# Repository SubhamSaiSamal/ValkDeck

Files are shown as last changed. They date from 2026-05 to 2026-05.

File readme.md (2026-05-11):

# VALKDECK 

Hey there, I'm Subham, a 14 year old kid (currently) from Chennai, India

I needed a better way to manage my flight sim telemetry, trigered automation workflows, and also blindly control my volume while locked into a game. I could have bought a generic macropad off Amazon for $20.

Instead, I spent 40 hours learning KiCad, routing my own custom PCB, designing an enclosure in onshape, and writing a CircuitPython program from scratch.

Welcome to *ValkDeck.*

It's a 9-key, fully hotswappable cyberdeck module powered by a Raspberry Pi Pico. It features per=key WS2812B underglow, a rotary encoder for media control, and a 0.91" I2C OLED display that feeds back live system status so I can actually know what my macros are doing.

ValkDeckFull

# FEATURE PIVOT

If you look at the top right of the board, you'll see a machined metal blanking plug.

Originally, that 12mm hole was meant for a massive, avionics-grade MTS-101 toggle switch (the "Nuke Switch") to act as a hardware reset. I measured the top plate perfectly. What i *forgot* to measure was the internal Z-axis clearance. The massive rectangular block of the toggle switch slammed right into the PCB.

Physical reality remains undefeated. Instead of spending the next 6 hours rearranging the whole top-case, I pivoted. I covered it with a sleek metal plug for a premium industrial look. It's not a bug; it's an aesthetic hardware change.

[OnshapeCase](https://cad.onshape.com/documents/f17dd9f4e6cb3dbe968d54ad/w/35238b8d1c489f2cc410f163/e/0b39d0bd7ba726a80e99828b)

# THE PCB

PCB

PCB_FRONT

PCB_BACK

I have been familiar with breadboards and scary jumper wire connections for quite a while. Instead of a terrifying 3D web of hand-soldered jumper wires, ValkDeck runs on a custom-routed, two layer FR-4 board.

Bottom-Mount SMD     : The kailh hotswap sockets and 1N4148 diodes are all surface mounted on the upperside of the board. 
Ghost-Free Matrix    : The diodes are correctly routed (Row to Column) to ensure complete N-key rollover without ghosting.
Through-Hole Anchors : The Raspberry Pi Pico, Rotary Encoder, and OLED screen are all through-hole soldered for maximum regidity 💪.

# HARDWARE

ValkDeck runs on a custom FR-4 PCB with a proper diode-protected switch matrix.

- The Brain   : Raspberry Pi Pico (RP2040)
- The Matrix  : 9x Kailh Hotswap Sockets (with 1N914 diodes pointing Row -> Col)
- The Display : 0.91" SSD1306 OLED (128x32)
- The Input   : 9x Mechanical Switches 
                 1x M274 Rotary Encoder (with push-to-mute)
- The RGB     : 9x WS2812B NeoPixels
- The Alert   : 1x Active Buzzer for audio feedback (and 8 bit pokemon and mario sfx)

# PINOUT ARCHITECTURE

If you're trying to understand the exact tracing or trying to make your very own ValkDeck, here is the routing:

| Component | Pico Pin (GPIO) | Note |
| :--- | :---: | ---: |
| Matrix Rows | GP09, GP10, GP11 | Row 0,1,2 |
| Matrix Cols | GP00, GP01, GP02 | Col 0,1,2 |
| Encoder | GP04(A), GP03(B), GND(C), GND(S2), GP05(S1)  | Volume sweeping and mute |
| OLED | GP16(SCL), GP17(SDA) | Standard I2C |
| NeoPixels | GP15 | Single data line for all 9 LEDs | 
| Buzzer | GP19 | PWM Audio (retro pokemon) |



9-WS2812B

3x3_Matrix

# RUNNING THE FIRMWARE

ValkBlox is run using Adafruit's CircuitPython. It uses the keypad library for the background matrix scanning, and displayio to dynamically update the OLED based on what macro you just fired

To Deploy : 

- Flash your Pico with the latest [CircuitPython.uf2](https://learn.adafruit.com/welcome-to-circuitpython/installing-circuitpython) 

- Grab the [Adafruit Library Bundle](https://github.com/adafruit/Adafruit_CircuitPython_Bundle) and drop this stuff into your CITCUITPY/lip folder
  - adafruit_hid
  - adafruit_displayio_ssd1306.mpy
  - adafruit_display_text
  - neopixel.mpy

- Drop firmware.py from this repo to the root drive

# BOM (Bill of materials)
|Name	 |Purpose	 |Quantity	|Total Cost (USD)	|Link	 |Distributor |
| :--- | :---: | --- | --- | --- |---
|Raspberry Pi PICO |Microcontroller (Controls everything lol)	 |1	 |$4.05	 |[View Product](https://www.silverlineelectronics.in/products/raspberry-pi-pico?_pos=3&_sid=a84e46afc&_ss=r#)	 |Silverzone |
|0.91 Inch I2C OLED 	|OLED Display to display backend info 	 |1	 |$1.94	 |[View Product](https://roboticsdna.in/product/0-91-inch-iic-4-pin-oled-display-module-ssd1306-white/)	|RoboticsDNA |
|Cherry MX RGB Switch	 |Brown RBG Switch (Pack of 10) 	|1	 |$3.7	 |[View Product](https://meckeys.com/shop/accessories/keyboard-accessories/key-switches/cherry-mx-rgb-switch/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)	|Meckeys |
|Kalih Socket |Hot-Swap socket for cherry mx switches (Pack of 10) |1	 |$0.84	 |[View Product](https://meckeys.com/shop/accessories/keyboard-accessories/key-switches/kailh-hot-swap-socket/)	|Meckeys |
|Deep Purple Keycaps |Purple Keycaps (Pack of 5) |2	 |$2.00	 |[View Product](https://meckeys.com/shop/accessories/keyboard-accessories/keycaps/blank-dsa-keycaps-1u/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)	|Meckeys |
|Rotary Encoder 	 |M274 Rotary Encoder Switch |1	 |$0.46	 |[View Product](https://robu.in/product/m274-360-degree-rotary-encoder-module-brick-sensor)	|Robu |
|rotary encoder knob 	 |3D printed |1	 |----	 |----- 	|----- |
|100nF capacitor 	 |100nF ceramic capacitor (Pack of 25) |1	 |$0.15	 |[View Product](https://roboticsdna.in/product/0-1-uf-ceramic-capacitor-10-pieces/)	|roboticsDNA |
|1N4148 Diode |IN4148 DIODE (Pack of 10) |2	 |$0.50 |[View Product](https://roboticsdna.in/product/diode-1n4148/)	|RoboticsDNA |
|WS2812B RGB 	 |WS2812B 5050RGB (Pack of 10) |1	 |$2.43	 |[View Product](https://robu.in/product/ws2812b-rgb-addressable-led-module)	|Robu |
|AC1255 Buzzer 	 |Buzzer |1	 |$0.074	 |[View Product](https://robu.in/product/ac1255-cldz-piezoelectric-passive-buzzer-1-25v12x5-5mm)	|Robu |
|2.54mm male header 	 |Male header for PICO |2 |$0.55	 |[View Product](https://robu.in/product/ds1029-01-1x40p8bva1-b-connfly-1x40-pin-2-54mm-pin-header-single-row-stack-v-t-type)	|Robu |
|Custom PCB 	 |Custom PCB printed from JLCPCB (includes shipping) |5	 |$9.20	 |[View Product](https://www.silverlineelectronics.in/products/raspberry-pi-pico?_pos=3&_sid=a84e46afc&_ss=r#)	 |Silverzone |
|Total 	 |----- |0 |$25.82 |----- 	|----- |



(ps. this repo will be updated to v1.1 after i build this board irl, stay tuned! :3)

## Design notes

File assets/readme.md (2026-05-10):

# VALKDECK 

Hey there, I'm Subham, a 14 year old kid (currently) from Chennai, India

I needed a better way to manage my flight sim telemetry, trigered automation workflows, and also blindly control my volume while locked into a game. I could have bought a generic macropad off Amazon for $20.

Instead, I spent 40 hours learning KiCad, routing my own custom PCB, designing an enclosure in onshape, and writing a CircuitPython program from scratch.

Welcome to *ValkDeck.*

It's a 9-key, fully hotswappable cyberdeck module powered by a Raspberry Pi Pico. It features per=key WS2812B underglow, a rotary encoder for media control, and a 0.91" I2C OLED display that feeds back live system status so I can actually know what my macros are doing.

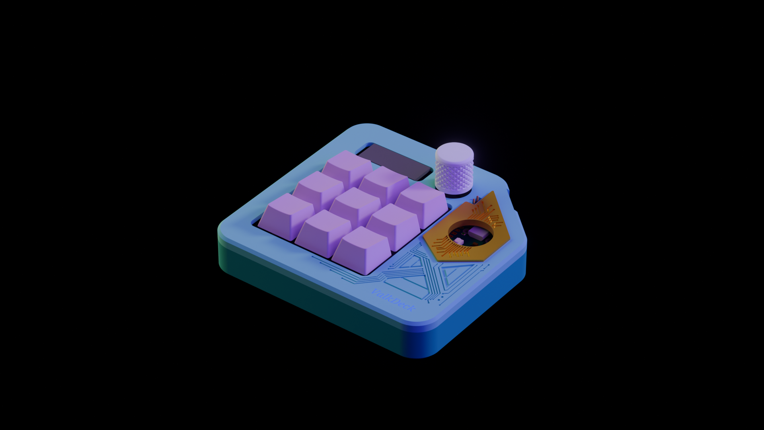
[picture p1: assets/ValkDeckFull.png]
ValkDeck! :D


# FEATURE PIVOT

If you look at the top right of the board, you'll see a machined metal blanking plug.

Originally, that 12mm hole was meant for a massive, avionics-grade MTS-101 toggle switch (the "Nuke Switch") to act as a hardware reset. I measured the top plate perfectly. What i *forgot* to measure was the internal Z-axis clearance. The massive rectangular block of the toggle switch slammed right into the PCB.

Physical reality remains undefeated. Instead of spending the next 6 hours rearranging the whole top-case, I pivoted. I covered it with a sleek metal plug for a premium industrial look. It's not a bug; it's an aesthetic hardware change.

# THE PCB

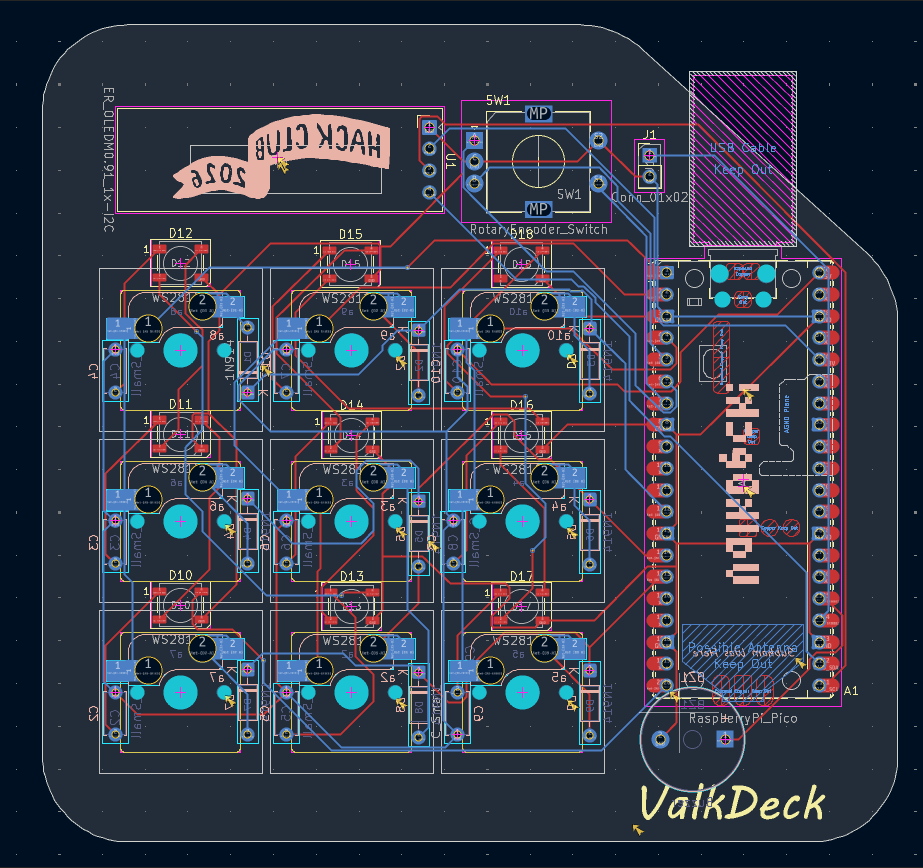
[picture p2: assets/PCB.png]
PCB in KiCad

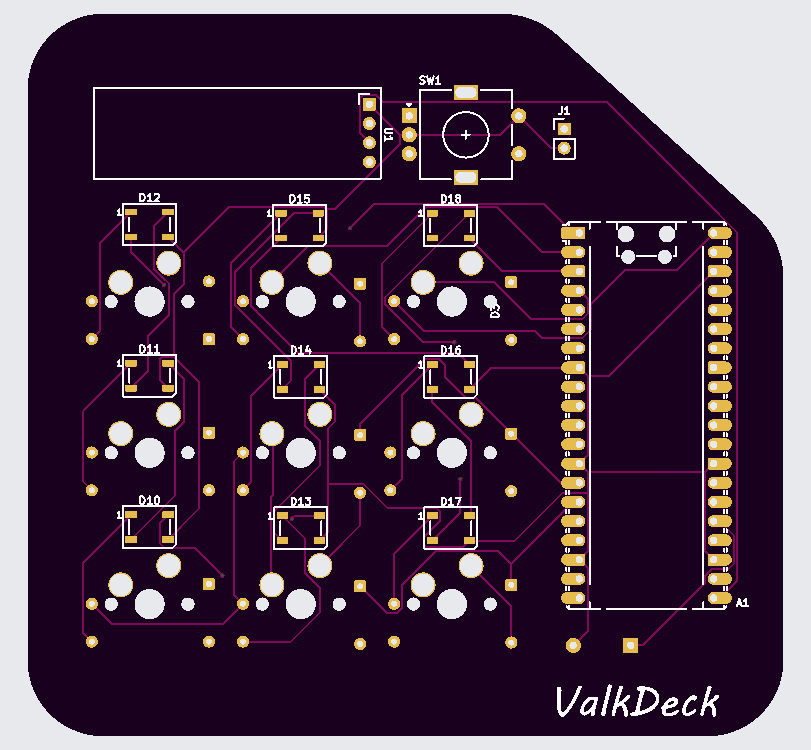
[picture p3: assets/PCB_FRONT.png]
PCB Front

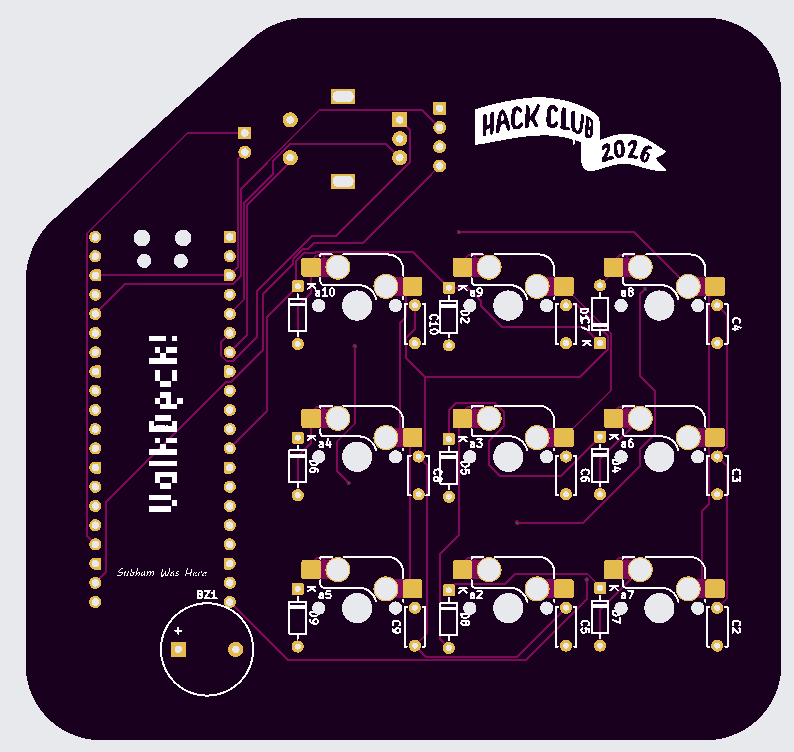
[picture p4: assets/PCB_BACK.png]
PCB Back


I have been familiar with breadboards and scary jumper wire connections for quite a while. Instead of a terrifying 3D web of hand-soldered jumper wires, ValkDeck runs on a custom-routed, two layer FR-4 board.

Bottom-Mount SMD     : The kailh hotswap sockets and 1N4148 diodes are all surface mounted on the upperside of the board. 
Ghost-Free Matrix    : The diodes are correctly routed (Row to Column) to ensure complete N-key rollover without ghosting.
Through-Hole Anchors : The Raspberry Pi Pico, Rotary Encoder, and OLED screen are all through-hole soldered for maximum regidity 💪.

# HARDWARE

ValkDeck runs on a custom FR-4 PCB with a proper diode-protected switch matrix.

- The Brain   : Raspberry Pi Pico (RP2040)
- The Matrix  : 9x Kailh Hotswap Sockets (with 1N914 diodes pointing Row -> Col)
- The Display : 0.91" SSD1306 OLED (128x32)
- The Input   : 9x Mechanical Switches 
                 1x M274 Rotary Encoder (with push-to-mute)
- The RGB     : 9x WS2812B NeoPixels
- The Alert   : 1x Active Buzzer for audio feedback (and 8 bit pokemon and mario sfx)

# PINOUT ARCHITECTURE

If you're trying to understand the exact tracing or trying to make your very own ValkDeck, here is the routing:

| Component | Pico Pin (GPIO) | Note |
| :--- | :---: | ---: |
| Matrix Rows | GP09, GP10, GP11 | Row 0,1,2 |
| Matrix Cols | GP00, GP01, GP02 | Col 0,1,2 |
| Encoder | GP04(A), GP03(B), GND(C), GND(S2), GP05(S1)  | Volume sweeping and mute |
| OLED | GP16(SCL), GP17(SDA) | Standard I2C |
| NeoPixels | GP15 | Single data line for all 9 LEDs | 
| Buzzer | GP19 | PWM Audio (retro pokemon) |

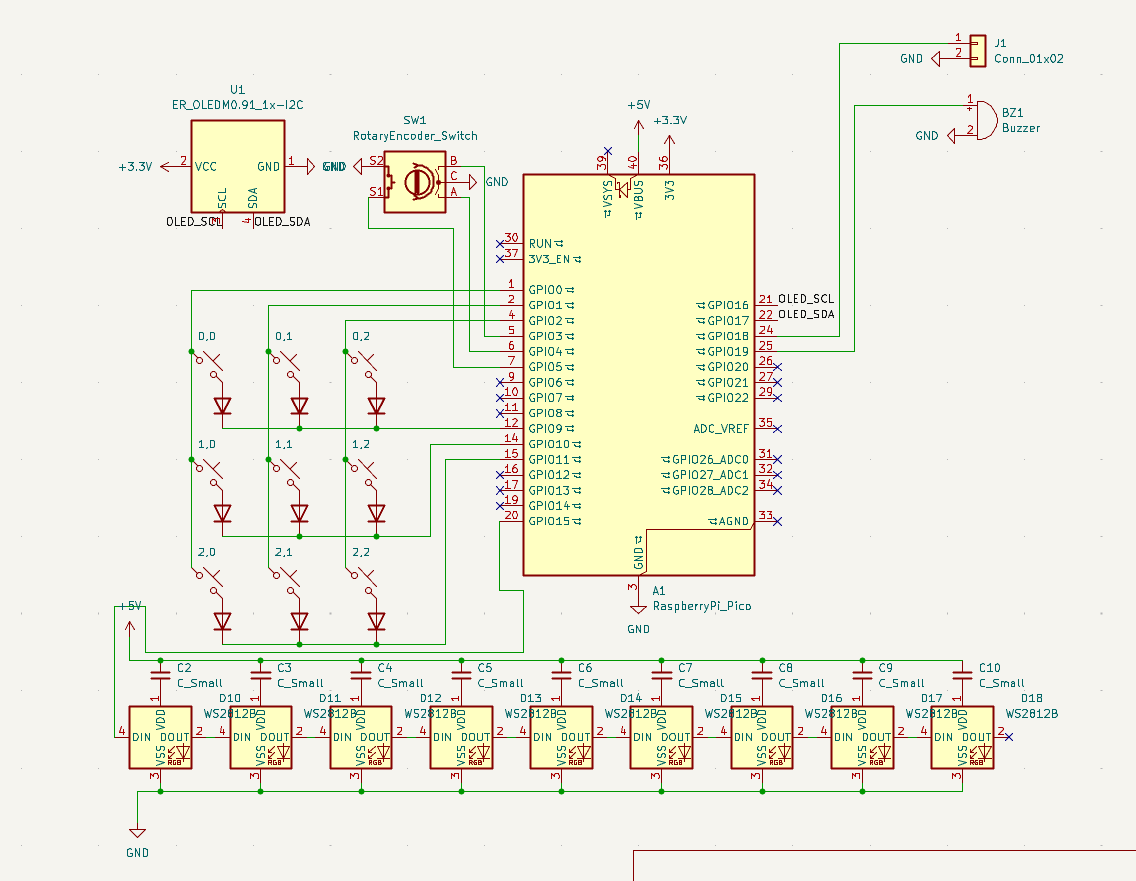
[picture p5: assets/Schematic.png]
Full Schematic

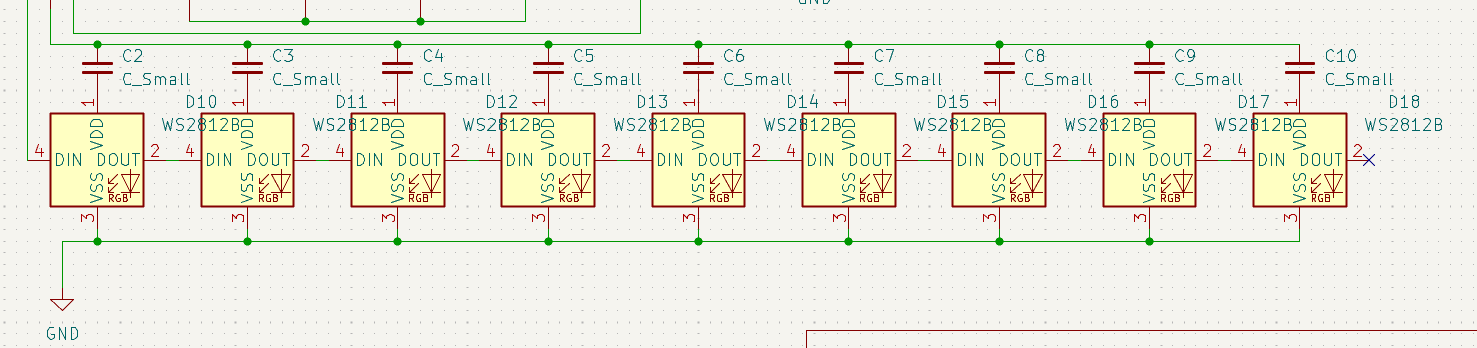
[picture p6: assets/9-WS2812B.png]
9-WS2812Bs

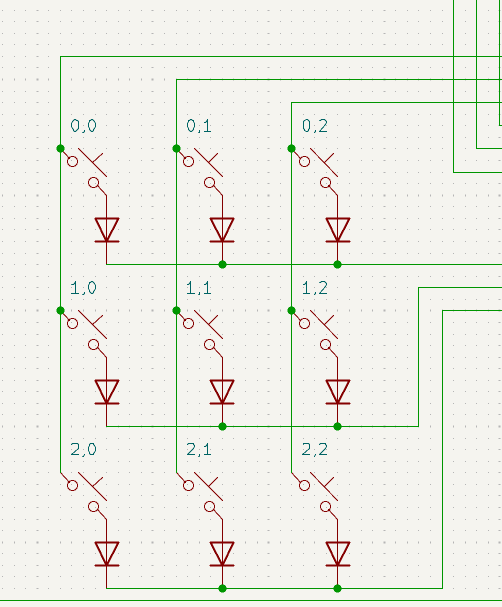
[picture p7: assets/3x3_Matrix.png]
3x3 Matrix


# RUNNING THE FIRMWARE

ValkBlox is run using Adafruit's CircuitPython. It uses the keypad library for the background matrix scanning, and displayio to dynamically update the OLED based on what macro you just fired

To Deploy : 

- Flash your Pico with the latest [CircuitPython.uf2](https://learn.adafruit.com/welcome-to-circuitpython/installing-circuitpython) 

- Grab the [Adafruit Library Bundle](https://github.com/adafruit/Adafruit_CircuitPython_Bundle) and drop this stuff into your CITCUITPY/lip folder
  - adafruit_hid
  - adafruit_displayio_ssd1306.mpy
  - adafruit_display_text
  - neopixel.mpy

- Drop firmware.py from this repo to the root drive

# BOM (Bill of materials)
|Name	 |Purpose	 |Quantity	|Total Cost (USD)	|Link	 |Distributor |
| :--- | :---: | --- | --- | --- |---
|Raspberry Pi PICO |Microcontroller (Controls everything lol)	 |1	 |$4.05	 |[View Product](https://www.silverlineelectronics.in/products/raspberry-pi-pico?_pos=3&_sid=a84e46afc&_ss=r#)	 |Silverzone |
|0.91 Inch I2C OLED 	|OLED Display to display backend info 	 |1	 |$1.94	 |[View Product](https://roboticsdna.in/product/0-91-inch-iic-4-pin-oled-display-module-ssd1306-white/)	|RoboticsDNA |
|Cherry MX RGB Switch	 |Brown RBG Switch (Pack of 10) 	|1	 |$3.7	 |[View Product](https://meckeys.com/shop/accessories/keyboard-accessories/key-switches/cherry-mx-rgb-switch/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)	|Meckeys |
|Kalih Socket |Hot-Swap socket for cherry mx switches (Pack of 10) |1	 |$0.84	 |[View Product](https://meckeys.com/shop/accessories/keyboard-accessories/key-switches/kailh-hot-swap-socket/)	|Meckeys |
|Deep Purple Keycaps |Purple Keycaps (Pack of 5) |2	 |$2.00	 |[View Product](https://meckeys.com/shop/accessories/keyboard-accessories/keycaps/blank-dsa-keycaps-1u/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)	|Meckeys |
|Rotary Encoder 	 |M274 Rotary Encoder Switch |1	 |$0.46	 |[View Product](https://robu.in/product/m274-360-degree-rotary-encoder-module-brick-sensor)	|Robu |
|rotary encoder knob 	 |3D printed |1	 |----	 |----- 	|----- |
|100nF capacitor 	 |100nF ceramic capacitor (Pack of 25) |1	 |$0.15	 |[View Product](https://roboticsdna.in/product/0-1-uf-ceramic-capacitor-10-pieces/)	|roboticsDNA |
|1N4148 Diode |IN4148 DIODE (Pack of 10) |2	 |$0.50 |[View Product](https://roboticsdna.in/product/diode-1n4148/)	|RoboticsDNA |
|WS2812B RGB 	 |WS2812B 5050RGB (Pack of 10) |1	 |$2.43	 |[View Product](https://robu.in/product/ws2812b-rgb-addressable-led-module)	|Robu |
|AC1255 Buzzer 	 |Buzzer |1	 |$0.074	 |[View Product](https://robu.in/product/ac1255-cldz-piezoelectric-passive-buzzer-1-25v12x5-5mm)	|Robu |
|2.54mm male header 	 |Male header for PICO |2 |$0.55	 |[View Product](https://robu.in/product/ds1029-01-1x40p8bva1-b-connfly-1x40-pin-2-54mm-pin-header-single-row-stack-v-t-type)	|Robu |
|Custom PCB 	 |Custom PCB printed from JLCPCB (includes shipping) |5	 |$9.20	 |[View Product](https://www.silverlineelectronics.in/products/raspberry-pi-pico?_pos=3&_sid=a84e46afc&_ss=r#)	 |Silverzone |
|Total 	 |----- |0 |$25.82 |----- 	|----- |

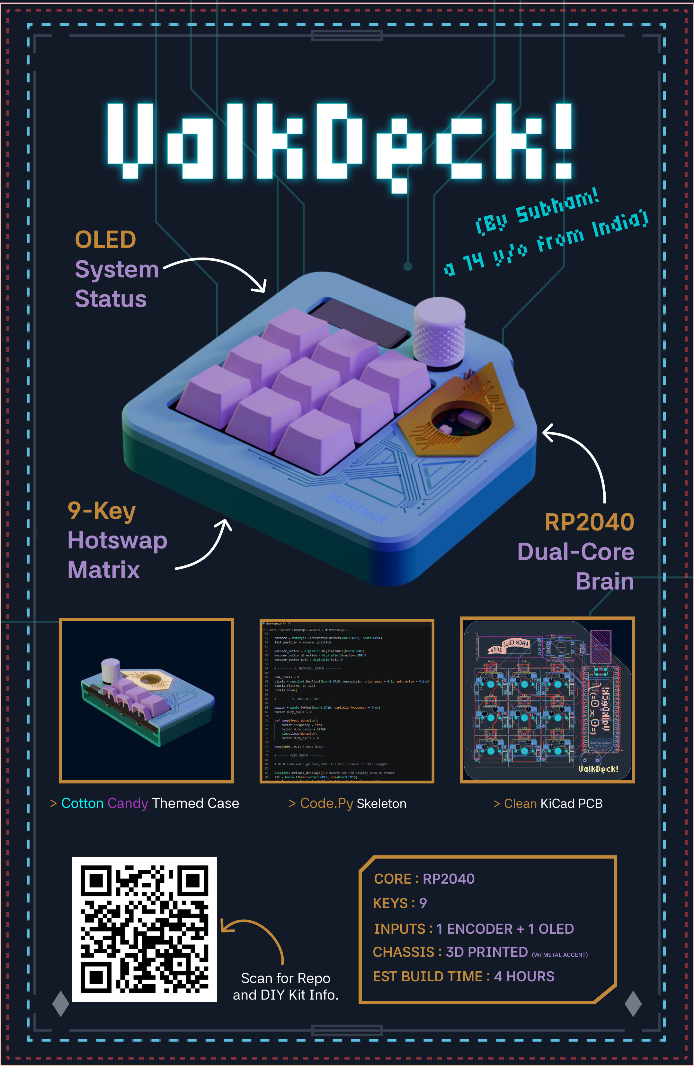
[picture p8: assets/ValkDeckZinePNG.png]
The zine for Fallout :D


(ps. this repo will be updated to v1.1 after i build this board irl, stay tuned! :3)

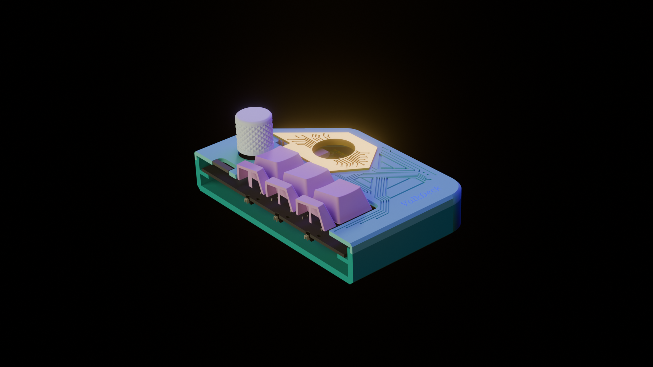
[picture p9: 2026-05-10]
assets/disected view.png

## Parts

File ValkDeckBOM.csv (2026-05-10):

ITEM | DESCRIPTION | QUANTITY | UNIT PRICE ($) | UNIT PRICE (?) | TOTAL PRICE ($) | TOTAL PRICE (?) | URL | RUNNING TOTAL ($ with tax)
Raspberry Pi PICO | Microcontroller | 1 | 3.43 | 325 | 3.43 | 325 | https://www.silverlineelectronics.in/products/raspberry-pi-pico?_pos=3&_sid=a84e46afc&_ss=r# | 4.05
0.91 Inch I2C OLED | OLED Display | 1 | 1.65 | 156 | 1.65 | 156 | https://roboticsdna.in/product/0-91-inch-iic-4-pin-oled-display-module-ssd1306-white/ | 1.94
Cherry MX switch | Brown RBG Switch (Pack of 10) | 1 | 3.7 | 350 | 3.7 | 350 | https://meckeys.com/shop/accessories/keyboard-accessories/key-switches/cherry-mx-rgb-switch/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 | 3.7
Kalih Socket | Hot-Swap socket (Pack of 10) | 1 | 0.84 | 80 | 0.84 | 80 | https://meckeys.com/shop/accessories/keyboard-accessories/key-switches/kailh-hot-swap-socket/ | 0.84
Deep Purple Keycaps | Keycaps (Pack of 5) | 2 | 1 | 95 | 2 | 190 | https://meckeys.com/shop/accessories/keyboard-accessories/keycaps/blank-dsa-keycaps-1u/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 | 2
Rotary Encoder | M274 Rotary Encoder Switch | 1 | 0.46 | 44 | 0.46 | 44 | https://robu.in/product/m274-360-degree-rotary-encoder-module-brick-sensor | 0.46
rotary encoder knob
100nF capacitor | 100nF ceramic capacitor (Pack of 25) | 1 | 0.13 | 12.38 | 0.13 | 12.38 | https://roboticsdna.in/product/0-1-uf-ceramic-capacitor-10-pieces/ | 0.15
1N4148 Diode | IN4148 DIODE (Pack of 10) | 2 | 0.21 | 20 | 0.42 | 40 | https://roboticsdna.in/product/diode-1n4148/ | 0.5
WS2812B RGB | WS2812B 5050RGB (Pack of 10) | 1 | 2.43 | 230 | 2.43 | 230 | https://robu.in/product/ws2812b-rgb-addressable-led-module | 2.43
AC1255 Buzzer | Buzzer | 1 | 0.074 | 7 | 0.074 | 7 | https://robu.in/product/ac1255-cldz-piezoelectric-passive-buzzer-1-25v12x5-5mm
2.54mm male header | Male header for PICO | 2 | 0.275 | 26 | 0.55 | 52 | https://robu.in/product/ds1029-01-1x40p8bva1-b-connfly-1x40-pin-2-54mm-pin-header-single-row-stack-v-t-type | 0.55
 |  |  |  |  | 15.684 | 1486.38 |  | 16.62

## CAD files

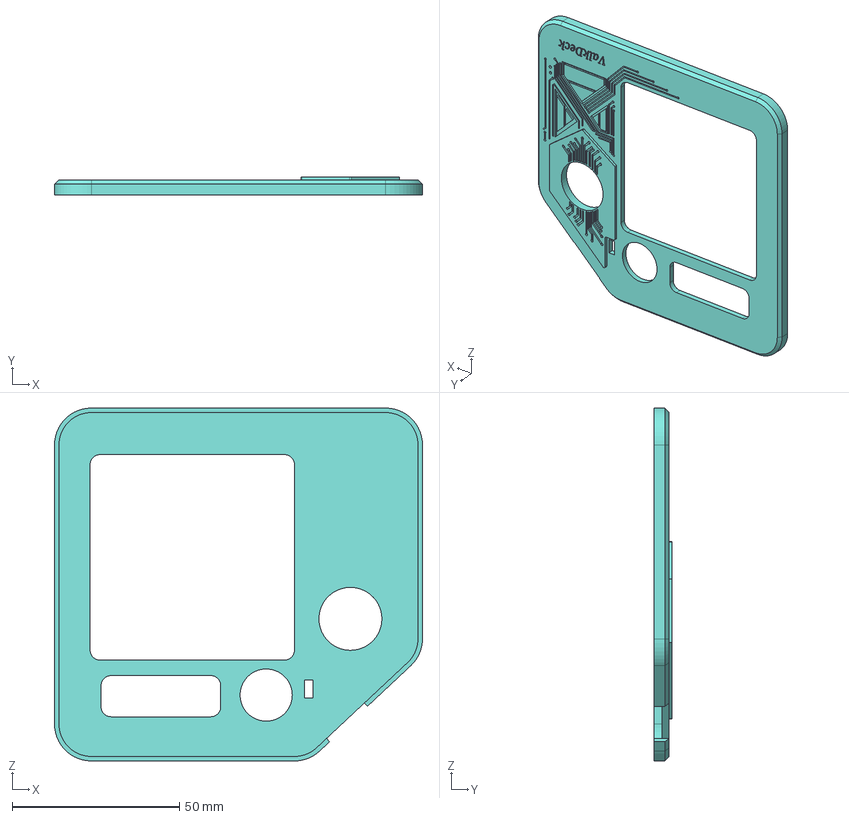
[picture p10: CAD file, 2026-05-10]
CAD/Top_Case.step
110.0 x 5.50 x 105.5 mm

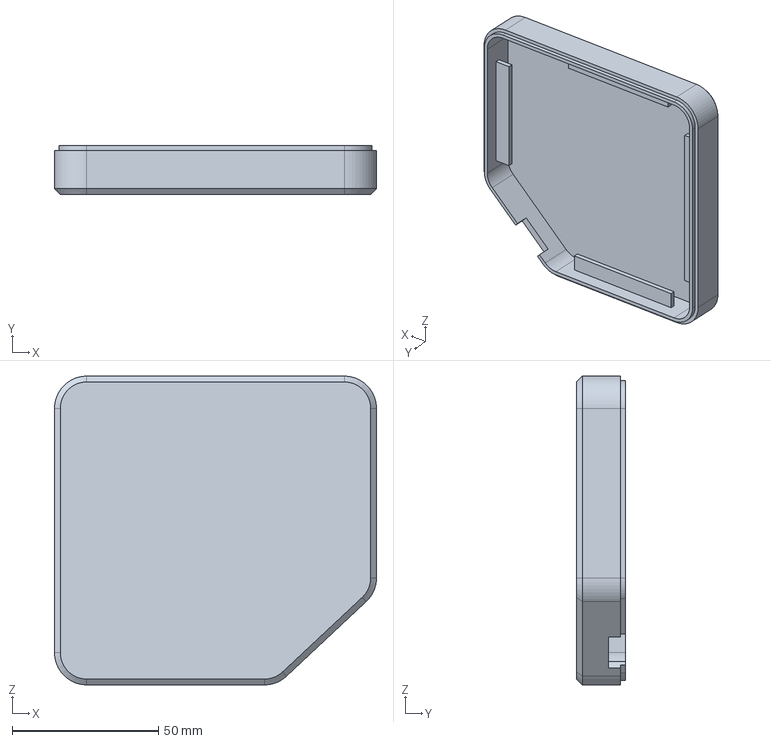
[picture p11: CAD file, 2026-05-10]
CAD/Case_Bottom.step
110.0 x 16.8 x 105.5 mm

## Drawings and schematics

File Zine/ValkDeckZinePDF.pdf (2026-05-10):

# ValkDeck! (By Subham!

# oLED

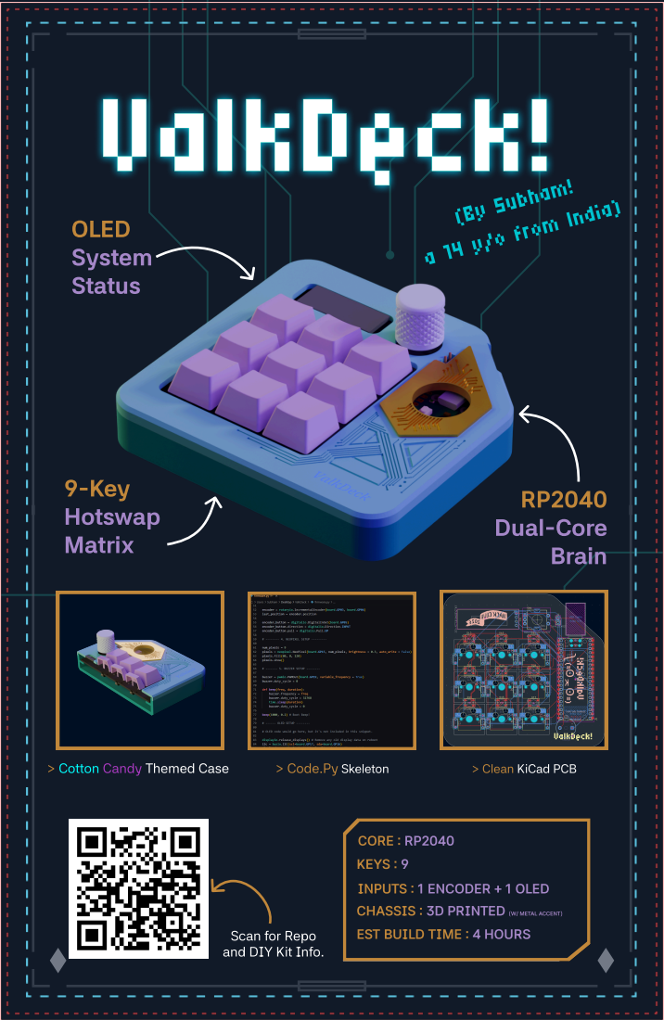
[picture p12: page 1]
a 14 y/o from India); 9-key; Hotswap; Matrix; System; Status; dual-Core; Brain; > Cotton Candy themed case; > code.py Skeleton; > clean KiCad PCB; KEYS : 9; CORE : RP2040

INPUTS : 1 ENCODER + 1 OLED

CHASSIS : 3D PRINTED (W/ METAL ACCENT)

EST BUILD TIME : 4 HOURS

Scan for Repo
and DIY Kit Info.

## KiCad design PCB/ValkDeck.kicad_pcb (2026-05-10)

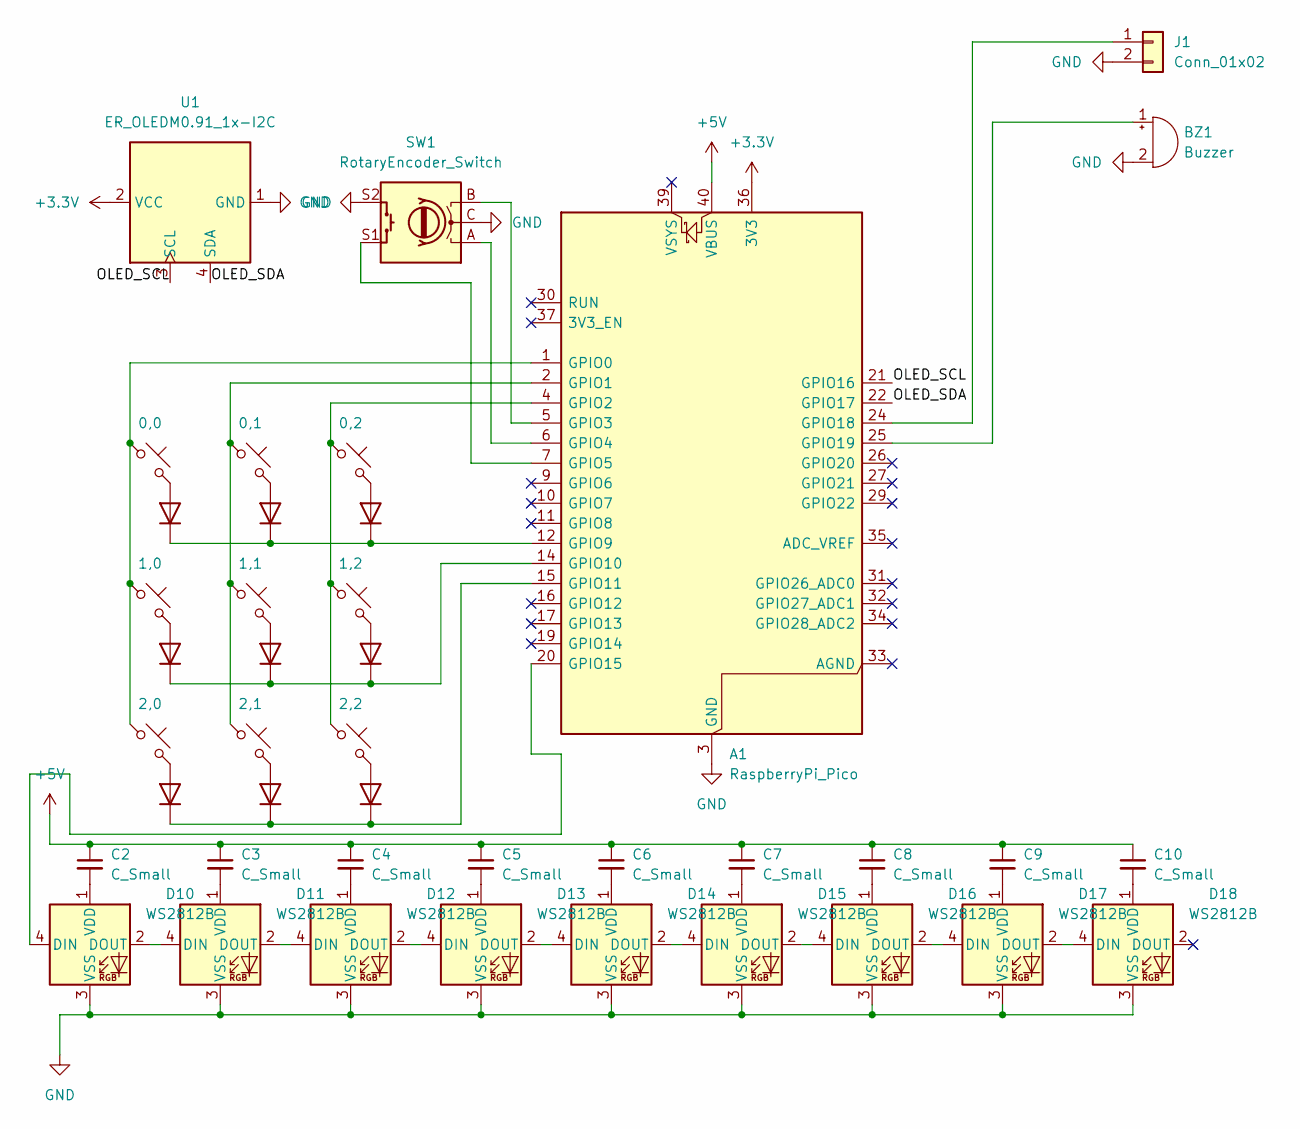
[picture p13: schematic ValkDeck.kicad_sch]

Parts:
A1: RaspberryPi_Pico; RaspberryPi_Pico_Common_Unspecified
BZ1: Buzzer; Buzzer_12x9.5RM7.6
C2, C3, C4, C5, C6, C7, C8, C9, C10: C_Small; C_Disc_D5.0mm_W2.5mm_P5.00mm
D1, D2, D3, D4, D5, D6, D7, D8, D9: 1N914; D_DO-35_SOD27_P7.62mm_Horizontal
D10, D11, D12, D13, D14, D15, D16, D17, D18: WS2812B; LED_WS2812B_PLCC4_5.0x5.0mm_P3.2mm
J1: Conn_01x02; PinHeader_1x02_P2.54mm_Vertical
SW1: RotaryEncoder_Switch; RotaryEncoder_Alps_EC11E-Switch_Vertical_H20mm
U1: ER_OLEDM0.91_1x-I2C
a2: 1,1; SW_MX_HS_CPG151101S11_1u
a3: 2,1; SW_MX_HS_CPG151101S11_1u
a4: 1,2; SW_MX_HS_CPG151101S11_1u
a5: 2,2; SW_MX_HS_CPG151101S11_1u
a6: 1,0; SW_MX_HS_CPG151101S11_1u
a7: 2,0; SW_MX_HS_CPG151101S11_1u
a8: 0,0; SW_MX_HS_CPG151101S11_1u
a9: 0,1; SW_MX_HS_CPG151101S11_1u
a10: 0,2; SW_MX_HS_CPG151101S11_1u

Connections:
+3.3V: A1.36 (3V3), U1.2 (VCC)
+5V: A1.40 (VBUS), C2.1, C3.1, C4.1, C5.1, C6.1, C7.1, C8.1, C9.1, C10.1
/OLED_SCL: A1.21 (GPIO16), U1.3 (SCL)
/OLED_SDA: A1.22 (GPIO17), U1.4 (SDA)
GND: A1.3 (GND), A1.8 (GND), A1.13 (GND), A1.18 (GND), A1.23 (GND), A1.28 (GND), A1.38 (GND), BZ1.2 (-), D10.3 (VSS), D11.3 (VSS), D12.3 (VSS), D13.3 (VSS), D14.3 (VSS), D15.3 (VSS), D16.3 (VSS), D17.3 (VSS), D18.3 (VSS), J1.2, SW1.C, SW1.S2, U1.1 (GND)
unnamed: A1.1 (GPIO0), a6.1, a7.1, a8.1
unnamed: A1.2 (GPIO1), a2.1, a3.1, a9.1
unnamed: A1.4 (GPIO2), a4.1, a5.1, a10.1
unnamed: A1.5 (GPIO3), SW1.B
unnamed: A1.6 (GPIO4), SW1.A
unnamed: A1.7 (GPIO5), SW1.S1
unnamed: A1.12 (GPIO9), D1.1 (K), D2.1 (K), D3.1 (K)
unnamed: A1.14 (GPIO10), D4.1 (K), D5.1 (K), D6.1 (K)
unnamed: A1.15 (GPIO11), D7.1 (K), D8.1 (K), D9.1 (K)
unnamed: A1.20 (GPIO15), D10.4 (DIN)
unnamed: A1.24 (GPIO18), J1.1
unnamed: A1.25 (GPIO19), BZ1.1 (+)
unnamed: D1.2 (A), a8.2
unnamed: D2.2 (A), a9.2
unnamed: D3.2 (A), a10.2
unnamed: D4.2 (A), a6.2
unnamed: D5.2 (A), a2.2
unnamed: D6.2 (A), a4.2
unnamed: D7.2 (A), a7.2
unnamed: D8.2 (A), a3.2
unnamed: D9.2 (A), a5.2
unnamed: D10.2 (DOUT), D11.4 (DIN)
unnamed: C2.2, D10.1 (VDD)
unnamed: D11.2 (DOUT), D12.4 (DIN)
unnamed: C3.2, D11.1 (VDD)
unnamed: D12.2 (DOUT), D13.4 (DIN)
unnamed: C4.2, D12.1 (VDD)
unnamed: D13.2 (DOUT), D14.4 (DIN)
unnamed: C5.2, D13.1 (VDD)
unnamed: D14.2 (DOUT), D15.4 (DIN)
unnamed: C6.2, D14.1 (VDD)
unnamed: D15.2 (DOUT), D16.4 (DIN)
unnamed: C7.2, D15.1 (VDD)
unnamed: D16.2 (DOUT), D17.4 (DIN)
unnamed: C8.2, D16.1 (VDD)
unnamed: D17.2 (DOUT), D18.4 (DIN)
unnamed: C9.2, D17.1 (VDD)
unnamed: C10.2, D18.1 (VDD)

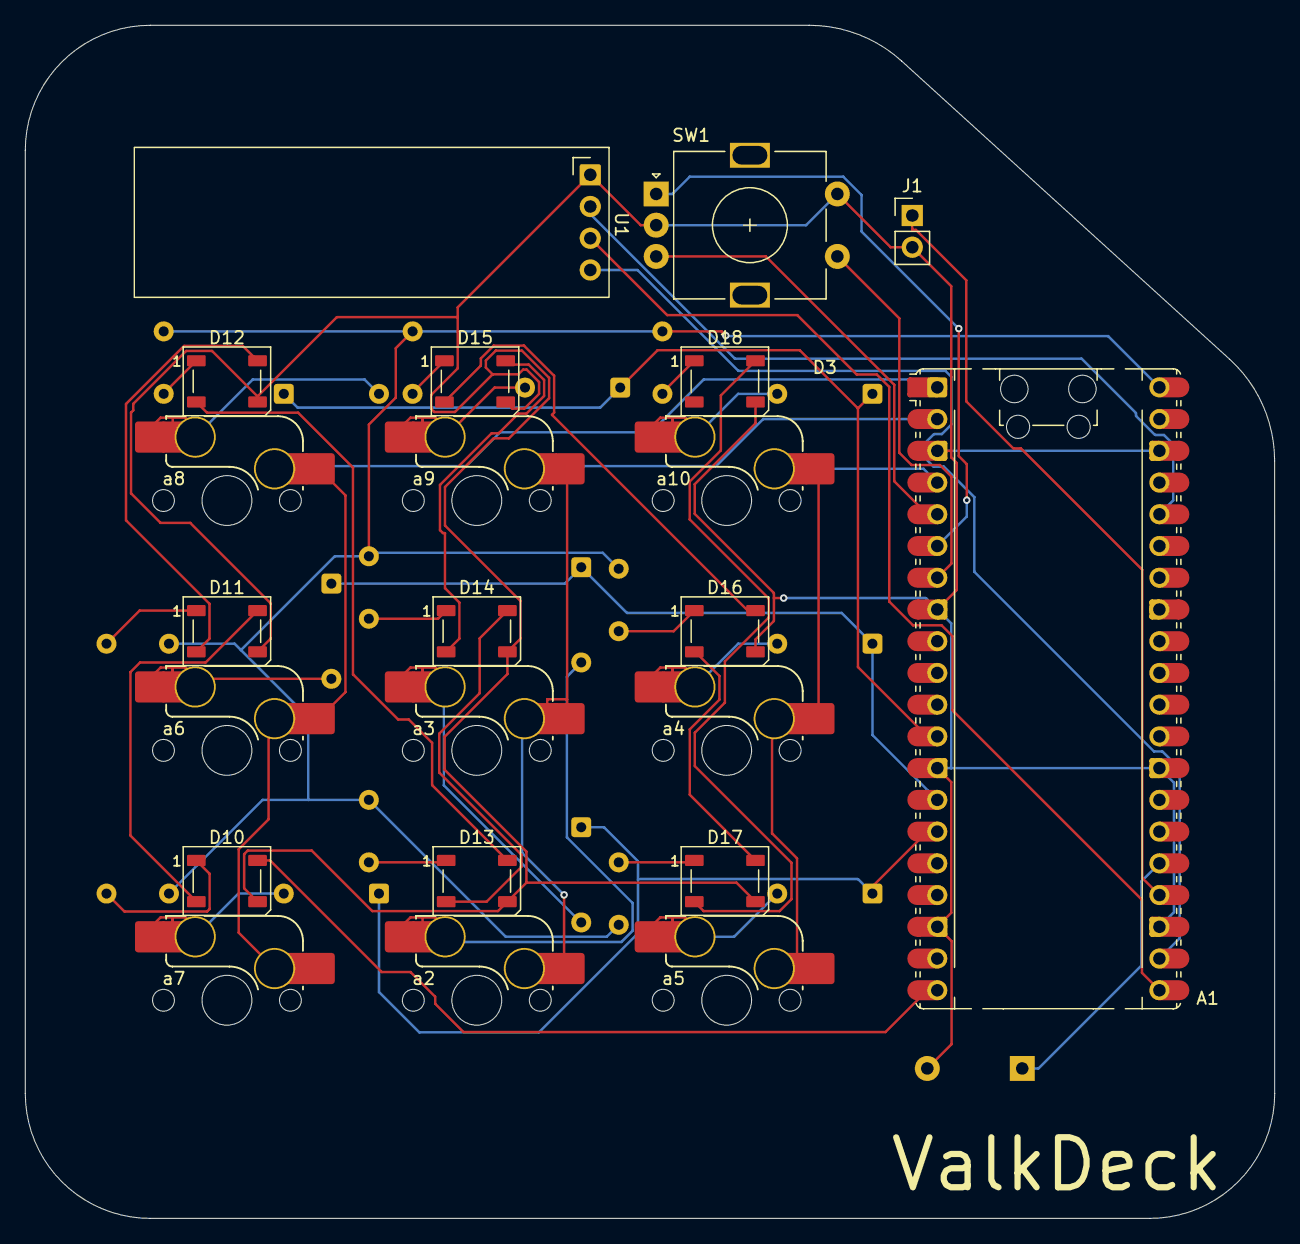
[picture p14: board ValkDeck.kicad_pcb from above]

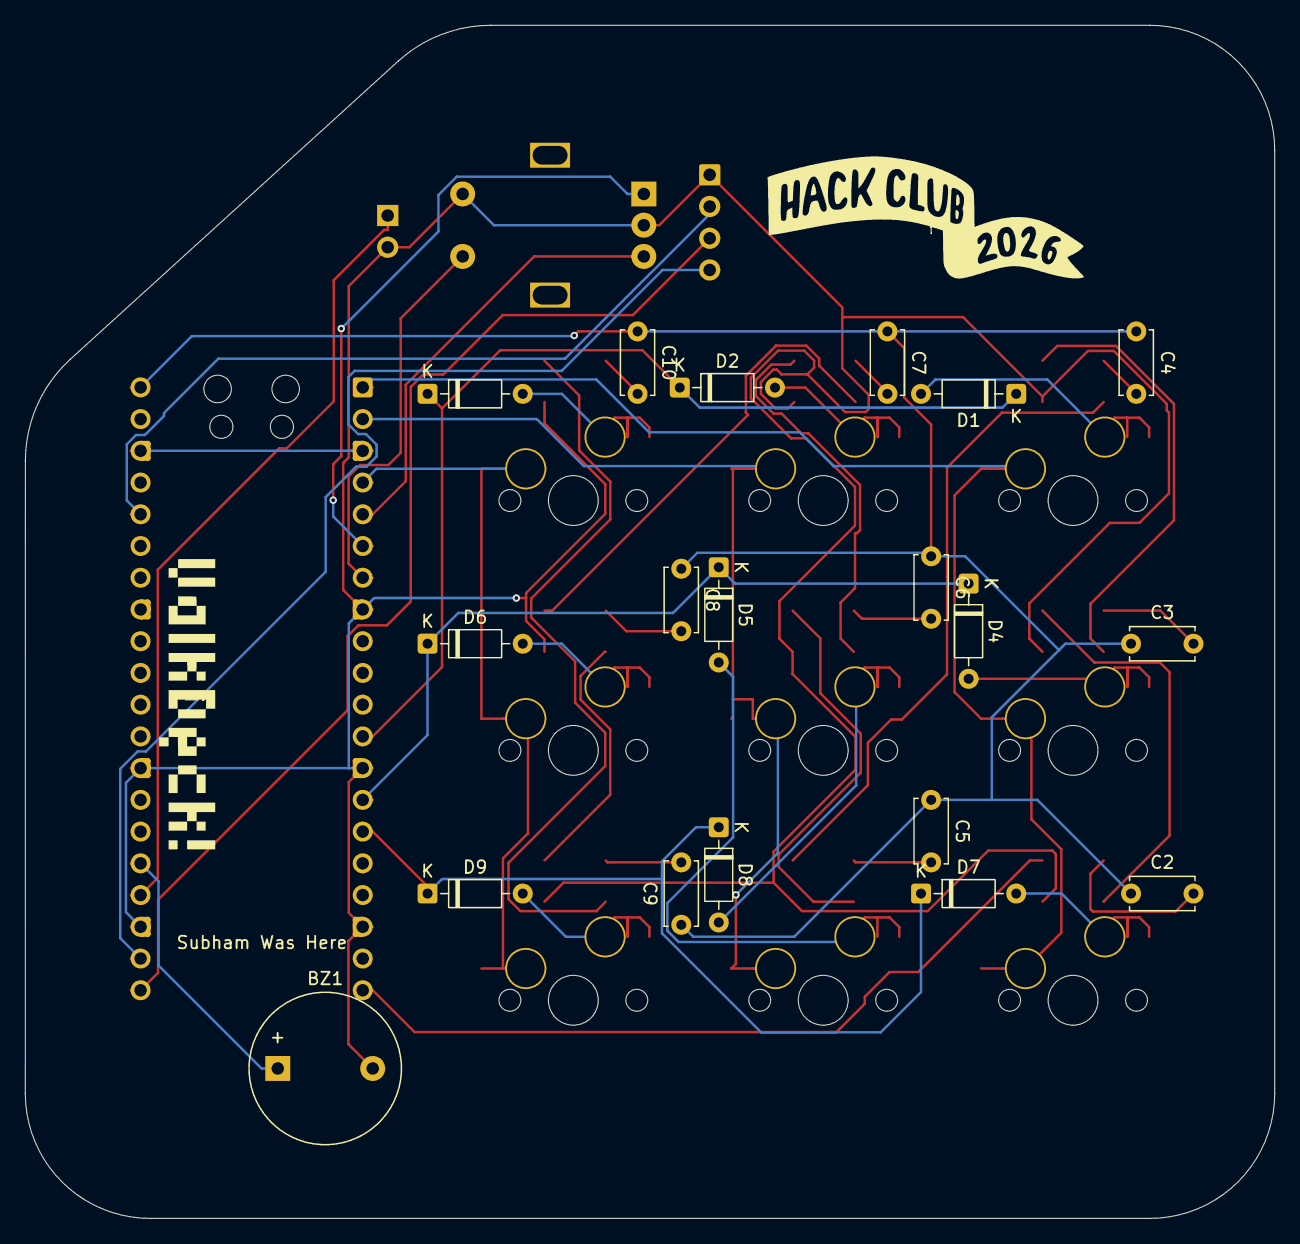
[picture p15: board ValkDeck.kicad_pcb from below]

Board: 2 copper layers, 100.0 x 95.5 mm, 43 parts (21 on the bottom side), 43 nets.

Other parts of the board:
g: LOGO; bannerfinal
i: LOGO; valkdeckie

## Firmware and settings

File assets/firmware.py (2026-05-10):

import time
import board
import busio
import digitalio
import usb_hid
import rotaryio
import neopixel
import keypad
import pwmio
import displayio
import adafruit_displayio_ssd1306
from adafruit_display_text import label
from adafruit_hid.keyboard import Keyboard
from adafruit_hid.keycode import Keycode
from adafruit_hid.consumer_control import ConsumerControl
from adafruit_hid.consumer_control_code import ConsumerControlCode


# ------ 1. USB HID SETUP -------
kbd = Keyboard(usb_hid.devices)
cc = ConsumerControl(usb_hid.devices)

# ------ 2. SWITCH MATRIX SETUP -------

# Diodes are pointing from row to column (cathode to anode)

row_pins = (board.GP09, board.GP10, board.GP11)
col_pins = (board.GP00, board.GP01, board.GP02)

keys = keypad.KeyMatrix(
    row_pins = row_pins,
    column_pins = col_pins,
    columns_to_rows = False
)

# Keymap for the 3x3 matrix

keymap = [
    Keycode.Q, Keycode.W, Keycode.E, #Row 0
    Keycode.A, Keycode.S, Keycode.D, #Row 1
    Keycode.Z, Keycode.X, Keycode.C, #Row 2
]

# Name to be shown on the OLED when pressed

key_names = ["Macro : Q", "Macro : W", "Macro : E",
             "Macro : A", "Macro : S", "Macro : D",
             "Macro : Z", "Macro : X", "Macro : C"]

# ------ 3. ROTARY ENCODER SETUP --------

encoder = rotaryio.IncrementalEncoder(board.GP03, board.GP04)
last_position = encoder.position

encoder_button = digitalio.DigitalInOut(board.GP05)
encoder_button.direction = digitalio.Direction.INPUT
encoder_button.pull = digitalio.Pull.UP

# -------- 4. NEOPIXEL SETUP ---------

num_pixels = 9
pixels = neopixel.NeoPixel(board.GP15, num_pixels, brightness = 0.3, auto_write = False)
pixels.fill(80, 0, 120) 
pixels.show()

# ------- 5. BUZZER SETUP --------

buzzer = pwmio.PWMOut(board.GP19, variable_frequency = True)
buzzer.duty_cycle = 0

def beep(freq, duration):
    buzzer.frequency = freq
    buzzer.duty_cycle = 32768
    time.sleep(duration)
    buzzer.duty_cycle = 0

beep(1000, 0.2) # Boot Beep!

# ------ OLED SETUP --------

# OLED code would go here, but it's not included in this snippet.

displayio.release_displays() # Remove any old display data on reboot
i2c = busio.I2C(scl=board.GP17, sda=board.GP16)
display_bus = displayio.I2CDisplay(i2c, device_address=0x3C)
display = adafruit_displayio_ssd1306.SSD1306(display_bus, width = 128, height = 32)

# Create the display content

splash = displayio.Group()
display.root_group = splash

# Set up the text label

text_area = label.Label(terminalio.FONT, text="VALKDECK OS v1.0", color=0xFFFFFF, x=10, y=15)
splash.append(text_area)

beep(1000, 0.1) # System Ready Beep!
time.sleep(1) # Leave the boot
text_area.text = "Ready for Action!"

# ------ MAIN LOOP --------

while True:
    
    # 1.Read the matrix keys
    
    event = keys.events.get()
    if event:
        key_index = event.key_index
        if event.pressed:
            print(f"Key {key_index} pressed")
            kbd.press(keymap[key_index])
            # Make the LED under the key turn teal when pressed
            pixels[key_index] = (0, 255, 255)
            pixels.show()
        if event.released:
            print(f"Key {key_index} release")
            kbd.release(keymap[key_index])
            # Make the LED under the key turn purple when pressed
            pixels[key_index] = (80, 0, 120)
            pixels.show()
    
    # 2. Read the Rotary Encoder Turns (Volume Control)
    
    current_position = encoder.position
    if current_position > last_position:
        cc.send(ConsumerControlCode.VOLUME_INCREMENT)
        last_position = current_position
    elif current_position < last_position:
        cc.send(ConsumerControlCode.VOLUME_DECREMENT)
        last_position = current_position

    # 3. Read the Rotary Encoder Button (Mute Toggle)

    if not encoder_button.value:
        cc.send(ConsumerControlCode.MUTE)

        # Make all the LEDs turn teal when the button is pressed
        
        pixels.fill((0, 255, 255))
        pixels.show()
        time.sleep(0.2)
        
        # Restore the LED colours after the button press
        
        for i in range(num_pixels):
            pixels[i] = (80, 0, 120)
        pixels.show()

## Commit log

2026-05-10 organized assets
    [ValkDeckBOM.csv]
2026-05-10 removed duplicates
    [ValkDeckBOM.csv]
2026-05-10 Enhance readme with more images of ValkDeck
    Added additional images to the readme for better visual representation of the ValkDeck features and PCB.
